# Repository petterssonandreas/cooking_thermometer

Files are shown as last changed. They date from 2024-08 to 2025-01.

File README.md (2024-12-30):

# cooking_thermometer

Simple electronics and SW project for creating a digital cooking/meat thermometer.

A probe from an old broken thermometer is used. The probe appears to be an NTC with around 200k resistance at 25C. Tests done at different temps to get a curve for the probe, curve can be found in `adc.c`.

The probe is connected to the HW via a 2.5mm "mono" jack with tip detection.

The processor used is an STM32G0B0KE with 512 kB flash and 144 kB SRAM. It comes in a LQFP32 package.

The product is powered via USB or via a 3.6V Li-ion battery, which is also charged when USB is connected. The battery is recycled from another old product. A small MCP73831 is used for the battery charging.

A small OLED display is used to display temperature and other info.

An active buzzer is used for the alarm functionality.

The system runs on 3.3 V.

# Zephyr installation

### Clone this repo
```
git clone git@github.com:petterssonandreas/cooking_thermometer.git
```

### Create a virtualenv, source it
```
python3 -m venv .venv
source .venv/Scripts/activate
```

### Install west
```
pip3 install west
```

### Init west with local repo, update
```
west init -l cooking_thermometer/
west update
```

### Export CMake
```
west zephyr-export
```

### Install packages
```
west packages pip --install
```

### Install Zephyr SDK
```
west sdk install
```

# Project build and flash
```
west build -p always -b ct_g0b0ke cooking_thermometer/apps/ct/
west flash
```

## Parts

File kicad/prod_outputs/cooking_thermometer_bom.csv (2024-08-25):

Id | Designator | Footprint | Quantity | Designation | Supplier and ref
1 | TP2 | TestPoint_Pad_D2.0mm | 1 | PC14
2 | R3,R6,R10 | R_1206_3216Metric_Pad1.30x1.75mm_HandSolder | 3 | 330
3 | SW4 | SW_PUSH_6mm | 1 | UI_B_SW
4 | R8,R9,R1,R2 | R_1206_3216Metric_Pad1.30x1.75mm_HandSolder | 4 | 100k
5 | SW5 | SW_PUSH_6mm | 1 | UI_C_SW
6 | U1 | LQFP-32_7x7mm_P0.8mm_Long_pads | 1 | STM32G0B0KETx
7 | C10,C3,C9 | C_1206_3216Metric_Pad1.33x1.80mm_HandSolder | 3 | 4.7uF
8 | J3 | PinHeader_1x02_P2.54mm_Vertical | 1 | 3V3_Power
9 | TP8 | TestPoint_Pad_D2.0mm | 1 | PB5
10 | R5 | R_1206_3216Metric_Pad1.30x1.75mm_HandSolder | 1 | 1k
11 | J4 | PinHeader_1x02_P2.54mm_Vertical | 1 | Battery
12 | C8,C4 | C_1206_3216Metric_Pad1.33x1.80mm_HandSolder | 2 | 100nF
13 | TP10 | TestPoint_Pad_D2.0mm | 1 | PB9
14 | D1 | D_DO-41_SOD81_P10.16mm_Horizontal | 1 | 1N5817
15 | D4 | LED_Rectangular_W5.0mm_H2.0mm | 1 | GREEN_LED_PWR
16 | J8 | Jack_Mono_2.5mm_with_Tip-Detect_Electrokit_41010270 | 1 | THERMO_CONN
17 | U3 | SOT-23-5_HandSoldering | 1 | MCP73831-2-OT
18 | U2 | TO-92_Inline | 1 | MCP1700x-330xxTO
19 | TP13 | TestPoint_Pad_D2.0mm | 1 | PA11/9
20 | J9 | USB_C_Receptacle_6P_TopMnt_Horizontal_Long_Pads_Electrokit_41021035 | 1 | USB_C
21 | TP9 | TestPoint_Pad_D2.0mm | 1 | PB8
22 | D3 | LED_Rectangular_W5.0mm_H2.0mm | 1 | RED_LED_CHARGING
23 | TP6 | TestPoint_Pad_D2.0mm | 1 | PB3
24 | TP5 | TestPoint_Pad_D2.0mm | 1 | PB1
25 | J2 | PinHeader_1x04_P2.54mm_Vertical | 1 | STLINK
26 | J7 | PinHeader_1x02_P2.54mm_Vertical | 1 | 5V_Power
27 | R7 | R_1206_3216Metric_Pad1.30x1.75mm_HandSolder | 1 | 4k7
28 | TP14 | TestPoint_Pad_D2.0mm | 1 | PA12/10
29 | R11 | R_1206_3216Metric_Pad1.30x1.75mm_HandSolder | 1 | 10k
30 | TP1 | TestPoint_Pad_D2.0mm | 1 | PC6
31 | BZ1 | Buzzer_12x9.5RM7.6 | 1 | Passive_Buzzer
32 | C2,C1 | C_1206_3216Metric_Pad1.33x1.80mm_HandSolder | 2 | 1uF
33 | Q1 | TO-92L_Inline_Wide | 1 | BC547
34 | TP4 | TestPoint_Pad_D2.0mm | 1 | PB0
35 | TP11 | TestPoint_Pad_D2.0mm | 1 | PA0
36 | SW1 | SW_PUSH_6mm | 1 | BOOT0_SW
37 | TP12 | TestPoint_Pad_D2.0mm | 1 | PA1
38 | TP15 | TestPoint_Pad_D2.0mm | 1 | PA15
39 | J1 | PinHeader_1x06_P2.54mm_Vertical | 1 | FTDI
40 | J6 | PinHeader_1x04_P2.54mm_Vertical | 1 | OLED_CONN
41 | R4 | R_1206_3216Metric_Pad1.30x1.75mm_HandSolder | 1 | 2k
42 | SW2 | SW_PUSH_6mm | 1 | NRST_SW
43 | TP3 | TestPoint_Pad_D2.0mm | 1 | PC15
44 | SW3 | SW_PUSH_6mm | 1 | UI_A_SW
45 | TP7 | TestPoint_Pad_D2.0mm | 1 | PB4
46 | D2 | LED_D4.0mm | 1 | WHITE_LED

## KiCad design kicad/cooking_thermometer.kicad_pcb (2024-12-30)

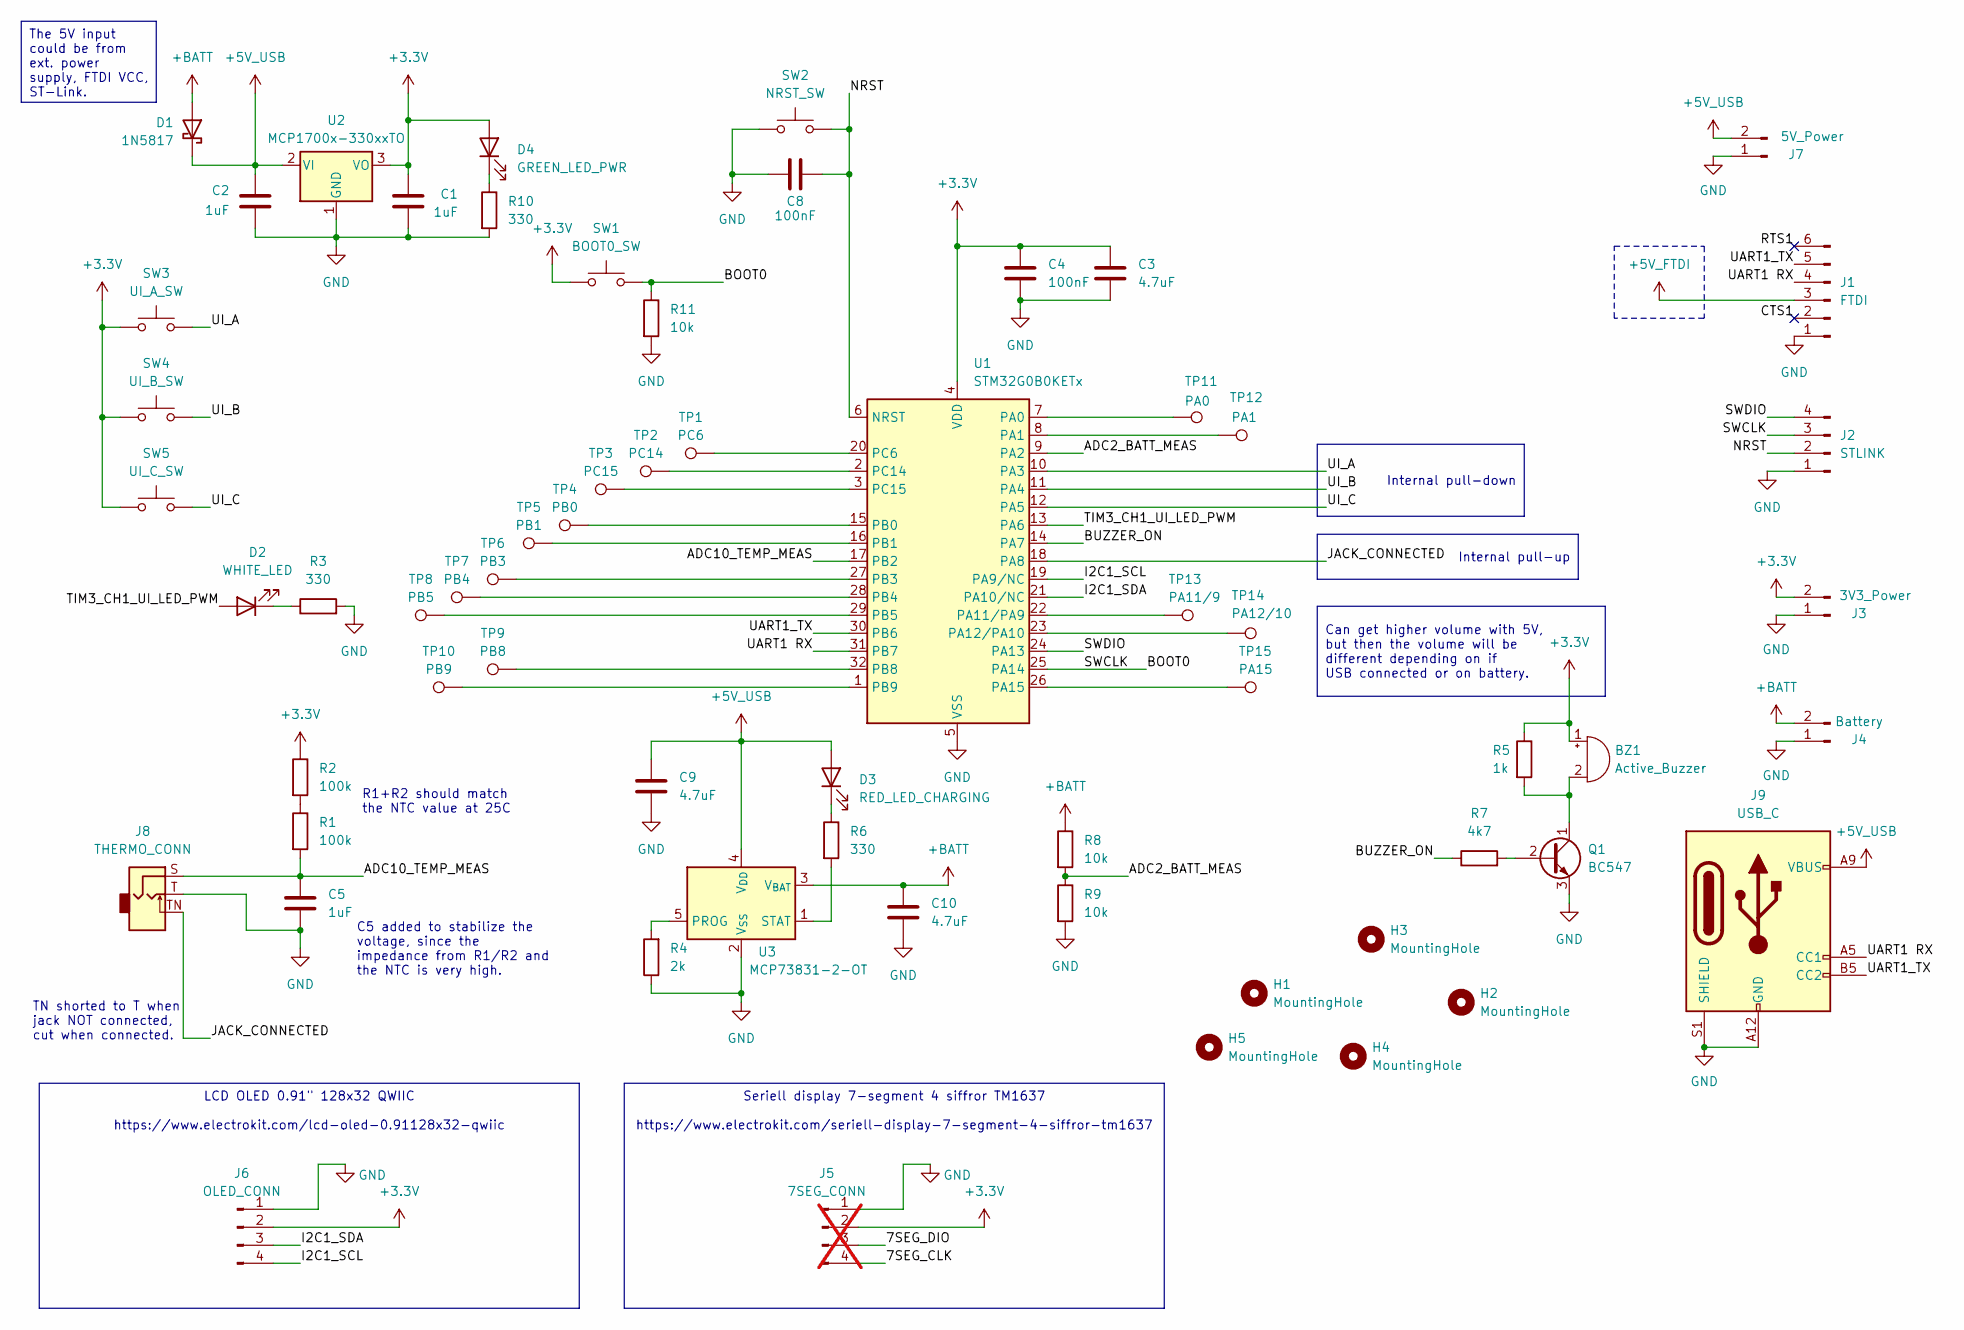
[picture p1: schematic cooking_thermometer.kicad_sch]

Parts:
BZ1: Active_Buzzer; Buzzer_12x9.5RM7.6
C1, C2, C5: 1uF; C_1206_3216Metric_Pad1.33x1.80mm_HandSolder
C3, C9, C10: 4.7uF; C_1206_3216Metric_Pad1.33x1.80mm_HandSolder
C4, C8: 100nF; C_1206_3216Metric_Pad1.33x1.80mm_HandSolder
D1: 1N5817; D_DO-41_SOD81_P10.16mm_Horizontal
D2: WHITE_LED; LED_D4.0mm
D3: RED_LED_CHARGING; LED_Rectangular_W5.0mm_H2.0mm
D4: GREEN_LED_PWR; LED_Rectangular_W5.0mm_H2.0mm
H1, H2, H3, H4, H5: MountingHole; MountingHole_3.2mm_M3
J1: FTDI; PinHeader_1x06_P2.54mm_Vertical
J2: STLINK; PinHeader_1x04_P2.54mm_Vertical
J3: 3V3_Power; PinHeader_1x02_P2.54mm_Vertical
J4: Battery; PinHeader_1x02_P2.54mm_Vertical
J5: 7SEG_CONN; PinSocket_1x04_P2.54mm_Vertical; not fitted
J6: OLED_CONN; PinHeader_1x04_P2.54mm_Vertical
J7: 5V_Power; PinHeader_1x02_P2.54mm_Vertical
J8: THERMO_CONN; Jack_Mono_2.5mm_with_Tip-Detect_Electrokit_41010270
J9: USB_C; USB_C_Receptacle_6P_TopMnt_Horizontal_Long_Pads_Electrokit_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
Q1: BC547; TO-92L_Inline_Wide
R1, R2: 100k; R_1206_3216Metric_Pad1.30x1.75mm_HandSolder
R3, R6, R10: 330; R_1206_3216Metric_Pad1.30x1.75mm_HandSolder
R4: 2k; R_1206_3216Metric_Pad1.30x1.75mm_HandSolder
R5: 1k; R_1206_3216Metric_Pad1.30x1.75mm_HandSolder
R7: 4k7; R_1206_3216Metric_Pad1.30x1.75mm_HandSolder
R8, R9, R11: 10k; R_1206_3216Metric_Pad1.30x1.75mm_HandSolder
SW1: BOOT0_SW; SW_PUSH_6mm
SW2: NRST_SW; SW_PUSH_6mm
SW3: UI_A_SW; SW_PUSH_6mm
SW4: UI_B_SW; SW_PUSH_6mm
SW5: UI_C_SW; SW_PUSH_6mm
TP1: PC6; TestPoint_Pad_D2.0mm
TP2: PC14; TestPoint_Pad_D2.0mm
TP3: PC15; TestPoint_Pad_D2.0mm
TP4: PB0; TestPoint_Pad_D2.0mm
TP5: PB1; TestPoint_Pad_D2.0mm
TP6: PB3; TestPoint_Pad_D2.0mm
TP7: PB4; TestPoint_Pad_D2.0mm
TP8: PB5; TestPoint_Pad_D2.0mm
TP9: PB8; TestPoint_Pad_D2.0mm
TP10: PB9; TestPoint_Pad_D2.0mm
TP11: PA0; TestPoint_Pad_D2.0mm
TP12: PA1; TestPoint_Pad_D2.0mm
TP13: PA11/9; TestPoint_Pad_D2.0mm
TP14: PA12/10; TestPoint_Pad_D2.0mm
TP15: PA15; TestPoint_Pad_D2.0mm
U1: STM32G0B0KETx; LQFP-32_7x7mm_P0.8mm_Long_pads
U2: MCP1700x-330xxTO; TO-92_Inline
U3: MCP73831-2-OT; SOT-23-5_HandSoldering

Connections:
+3.3V: BZ1.1 (+), C1.1, C3.1, C4.1, D4.2 (A), J3.2, J5.2, J6.2, R2.1, R5.1, SW1.1, SW3.1, SW4.1, SW5.1, U1.4 (VDD), U2.3 (VO)
+5V_FTDI: J1.3
+5V_USB: C2.1, C9.1, D1.1 (K), D3.2 (A), J7.2, J9.A9 (VBUS), J9.B9 (VBUS), U2.2 (VI), U3.4 (V_{DD})
+BATT: C10.1, D1.2 (A), J4.2, R8.1, U3.3 (V_{BAT})
/ADC2_BATT_MEAS: R8.2, R9.1, U1.9 (PA2)
/ADC10_TEMP_MEAS: C5.1, J8.S, R1.2, U1.17 (PB2)
/BOOT0: J2.3, R11.1, SW1.2, U1.25 (PA14)
/BUZZER_ON: R7.1, U1.14 (PA7)
/CTS1: J1.2
/I2C1_SCL: J6.4, U1.19 (PA9/NC)
/I2C1_SDA: J6.3, U1.21 (PA10/NC)
/JACK_CONNECTED: J8.TN, U1.18 (PA8)
/NRST: C8.2, J2.2, SW2.2, U1.6 (NRST)
/RTS1: J1.6
/SWDIO: J2.4, U1.24 (PA13)
/TIM3_CH1_UI_LED_PWM: D2.2 (A), U1.13 (PA6)
/UART1 RX: J1.4, J9.A5 (CC1), U1.31 (PB7)
/UART1_TX: J1.5, J9.B5 (CC2), U1.30 (PB6)
/UI_A: SW3.2, U1.10 (PA3)
/UI_B: SW4.2, U1.11 (PA4)
/UI_C: SW5.2, U1.12 (PA5)
GND: C1.2, C2.2, C3.2, C4.2, C5.2, C8.1, C9.2, C10.2, J1.1, J2.1, J3.1, J4.1, J5.1, J6.1, J7.1, J8.T, J9.A12 (GND), J9.B12 (GND), J9.S1 (SHIELD), Q1.3 (E), R3.2, R4.1, R9.2, R10.2, R11.2, SW2.1, U1.5 (VSS), U2.1 (GND), U3.2 (V_{SS})
unnamed: BZ1.2 (-), Q1.1 (C), R5.2
unnamed: D2.1 (K), R3.1
unnamed: D3.1 (K), R6.1
unnamed: D4.1 (K), R10.1
unnamed: Q1.2 (B), R7.2
unnamed: R1.1, R2.2
unnamed: TP11.1, U1.7 (PA0)
unnamed: TP12.1, U1.8 (PA1)
unnamed: TP13.1, U1.22 (PA11/PA9)
unnamed: TP14.1, U1.23 (PA12/PA10)
unnamed: TP15.1, U1.26 (PA15)
unnamed: TP4.1, U1.15 (PB0)
unnamed: TP5.1, U1.16 (PB1)
unnamed: TP6.1, U1.27 (PB3)
unnamed: TP7.1, U1.28 (PB4)
unnamed: TP8.1, U1.29 (PB5)
unnamed: TP9.1, U1.32 (PB8)
unnamed: TP10.1, U1.1 (PB9)
unnamed: TP1.1, U1.20 (PC6)
unnamed: TP2.1, U1.2 (PC14)
unnamed: TP3.1, U1.3 (PC15)
unnamed: R4.2, U3.5 (PROG)
unnamed: R6.2, U3.1 (STAT)

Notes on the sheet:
Can get higher volume with 5V, but then the volume will be different depending on if USB connected or on battery.
LCD OLED 0.91" 128x32 QWIIC https://www.electrokit.com/lcd-oled-0.91128x32-qwiic
Internal pull-down
Internal pull-up
The 5V input could be from ext. power supply, FTDI VCC, ST-Link.
Seriell display 7-segment 4 siffror TM1637 https://www.electrokit.com/seriell-display-7-segment-4-siffror-tm1637
TN shorted to T when jack NOT connected, cut when connected.
R1+R2 should match the NTC value at 25C
C5 added to stabilize the voltage, since the impedance from R1/R2 and the NTC is very high.

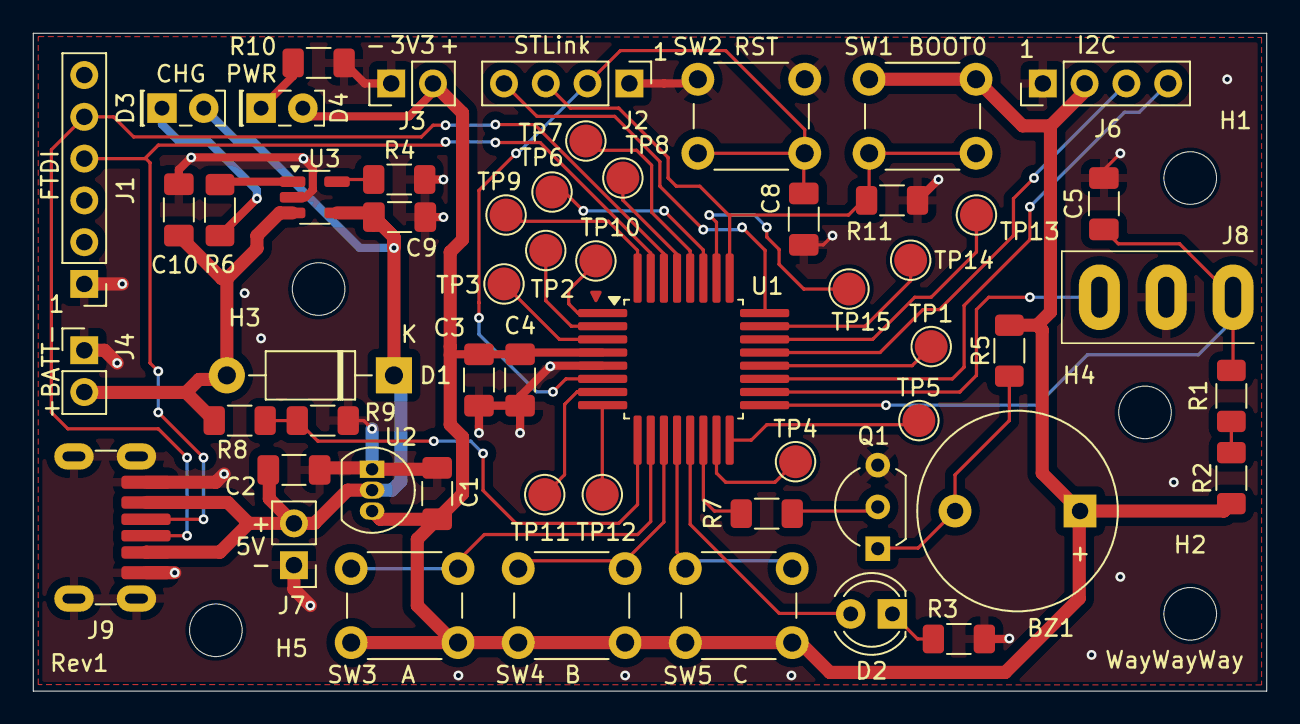
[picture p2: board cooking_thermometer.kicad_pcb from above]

Board: 2 copper layers, 75.0 x 40.0 mm, 61 parts (0 on the bottom side), 42 nets.

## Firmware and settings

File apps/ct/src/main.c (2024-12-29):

/*
 * Copyright (c) 2016 Open-RnD Sp. z o.o.
 * Copyright (c) 2020 Nordic Semiconductor ASA
 *
 * SPDX-License-Identifier: Apache-2.0
 */

#include "alarm.h"
#include "battery.h"
#include "state.h"
#include <zephyr/kernel.h>
#include <zephyr/device.h>
#include <zephyr/drivers/gpio.h>
#include <zephyr/drivers/pwm.h>
#include <zephyr/sys/util.h>
#include <zephyr/sys/printk.h>

#include <zephyr/logging/log.h>
LOG_MODULE_REGISTER(ct_main, CONFIG_CT_MAIN_LOG_LEVEL);

#include "adc.h"
#include "buttons.h"
#include "display.h"
#include "cttime.h"

static void set_target_temp_timer_expiry_function(struct k_timer *timer_id) {
    state_queue_entry_t queue_entry;
    queue_entry.event = STATE_EVENT_SET_TARGET_TEMP_TIMER_ELAPSED;
    if (k_msgq_put(&state_msgq, &queue_entry, K_NO_WAIT)) {
        LOG_WRN("Failed to put target temp timer event in msgq");
    }
}

K_TIMER_DEFINE(set_target_temp_timer, set_target_temp_timer_expiry_function, NULL);

static void check_inputs(void)
{
    state_queue_entry_t queue_entry;

    switch (state.state) {
    case STATE_IDLE:
        if (state.probe_connected && (state.temperature >= state.target_temperature)) {
            queue_entry.event = STATE_EVENT_TARGET_TEMP_REACHED;
            if (k_msgq_put(&state_msgq, &queue_entry, K_NO_WAIT)) {
                LOG_WRN("Failed to put target temp reached event in msgq");
            }
        }
        break;

    case STATE_TARGET_TEMP_REACHED:
    case STATE_TARGET_TEMP_REACHED_ACKED:
        if (!state.probe_connected || (state.temperature < state.target_temperature)) {
            queue_entry.event = STATE_EVENT_TARGET_TEMP_LOST;
            if (k_msgq_put(&state_msgq, &queue_entry, K_NO_WAIT)) {
                LOG_WRN("Failed to put target temp lost event in msgq");
            }
        }
        break;

    default:
        break;
    }
}

static void state_loop(void)
{
    int ret;
    state_queue_entry_t queue_entry;

    ret = k_msgq_get(&state_msgq, &queue_entry, K_MSEC(20));
    if (ret) {
        return;
    }

    switch (state.state) {
    case STATE_IDLE:
        switch (queue_entry.event) {
        case STATE_EVENT_BUTTON_PRESSED:
            if (queue_entry.data == 2) {
                state.state = STATE_SET_TARGET_TEMP;
                state_reset_blink_timer();
                k_timer_start(&set_target_temp_timer, K_SECONDS(5), K_NO_WAIT);
            }
            break;

        case STATE_EVENT_TARGET_TEMP_REACHED:
            state.state = STATE_TARGET_TEMP_REACHED;
            alarm_enable();
            break;

        default:
            break;
        }
        break;

    case STATE_TARGET_TEMP_REACHED:
        switch (queue_entry.event) {
        case STATE_EVENT_BUTTON_PRESSED:
            /* Allow any button to ack */
            state.state = STATE_TARGET_TEMP_REACHED_ACKED;
            alarm_disable();
            break;

        case STATE_EVENT_TARGET_TEMP_LOST:
            state.state = STATE_IDLE;
            alarm_disable();
            break;

        default:
            break;
        }
        break;

    case STATE_TARGET_TEMP_REACHED_ACKED:
        switch (queue_entry.event) {
        case STATE_EVENT_TARGET_TEMP_LOST:
            state.state = STATE_IDLE;
            alarm_disable();
            break;

        case STATE_EVENT_BUTTON_PRESSED:
            if (queue_entry.data == 2) {
                state.state = STATE_SET_TARGET_TEMP;
                state_reset_blink_timer();
                k_timer_start(&set_target_temp_timer, K_SECONDS(5), K_NO_WAIT);
            }
            break;

        default:
            break;
        }
        break;

    case STATE_SET_TARGET_TEMP:
        switch (queue_entry.event) {
        case STATE_EVENT_BUTTON_PRESSED:
            if (queue_entry.data == 0) {
                state.target_temperature++;
                state_reset_blink_timer();
                k_timer_start(&set_target_temp_timer, K_SECONDS(5), K_NO_WAIT);
            }
            else if (queue_entry.data == 1) {
                state.target_temperature--;
                state_reset_blink_timer();
                k_timer_start(&set_target_temp_timer, K_SECONDS(5), K_NO_WAIT);
            }
            else if (queue_entry.data == 2) {
                state.state = STATE_IDLE;
                k_timer_stop(&set_target_temp_timer);
            }
            break;

        case STATE_EVENT_SET_TARGET_TEMP_TIMER_ELAPSED:
            state.state = STATE_IDLE;
            break;

        default:
            break;
        }
        break;

    default:
        __ASSERT(false, "Bad state: %d", state.state);
        break;
    }
}

int main(void)
{
    int ret;

    LOG_INF("main starting");

    ret = state_init();
    if (ret) {
        LOG_ERR("Error %d: failed to init state", ret);
        return ret;
    }
    LOG_INF("state init done");

    ret = alarm_init();
    if (ret) {
        LOG_ERR("Error %d: failed to init alarm", ret);
        return ret;
    }
    LOG_INF("alarm init done");

    ret = buttons_init();
    if (ret != 0) {
        LOG_ERR("Error %d: failed to init buttons", ret);
        return ret;
    }
    LOG_INF("buttons init done");

    ret = cttime_init();
    if (ret) {
        LOG_ERR("Error %d: failed to init time", ret);
        return ret;
    }
    LOG_INF("Time init done");

    ret = adc_init();
    if (ret) {
        LOG_ERR("Error %d: failed to init ADC", ret);
        return ret;
    }
    LOG_INF("ADC init done");

    ret = battery_init();
    if (ret) {
        LOG_ERR("Error %d: failed to init battery", ret);
        return ret;
    }
    LOG_INF("battery init done");

    ret = display_init();
    if (ret) {
        LOG_ERR("Error %d: failed to init display", ret);
        return ret;
    }
    LOG_INF("Display init done");

    state.state = STATE_IDLE;

    while (true) {
        state_loop();
        check_inputs();
    }

    return 0;
}

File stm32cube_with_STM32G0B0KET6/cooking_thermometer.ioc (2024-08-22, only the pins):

Mcu.UserName=STM32G0B0KETx
PA10.Signal=I2C1_SDA
PA13.Signal=SYS_SWDIO
PA14-BOOT0.Signal=SYS_SWCLK
PA2.Signal=ADC1_IN2
PA3.GPIO_Label=UI_A
PA3.Signal=GPIO_Input
PA4.GPIO_Label=UI_B
PA4.Signal=GPIO_Input
PA5.GPIO_Label=UI_C
PA5.Signal=GPIO_Input
PA6.GPIO_Label=UI_LED
PA6.Signal=GPIO_Output
PA7.Signal=S_TIM3_CH2
PA8.GPIO_Label=nJACK_CONN
PA8.Signal=GPIO_Input
PA9.Signal=I2C1_SCL
PB2.Signal=ADC1_IN10
PB6.Signal=USART1_TX
PB7.Signal=USART1_RX

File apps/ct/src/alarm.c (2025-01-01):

#include "alarm.h"
#include "state.h"
#include <zephyr/kernel.h>
#include <zephyr/device.h>
#include <zephyr/drivers/pwm.h>
#include <zephyr/drivers/gpio.h>
#include <zephyr/sys/util.h>

#include <zephyr/logging/log.h>
LOG_MODULE_REGISTER(ct_alarm, CONFIG_CT_ALARM_LOG_LEVEL);

#define PWM_LED_PERIOD NSEC_PER_MSEC

#define ALARM_ON_TIME_MSEC 50
#define ALARM_OFF_TIME_MSEC 950

static const struct pwm_dt_spec ui_led = PWM_DT_SPEC_GET(DT_ALIAS(uiled));
static const struct gpio_dt_spec buzzer = GPIO_DT_SPEC_GET(DT_ALIAS(buzzer), gpios);

static struct k_timer alarm_timer;

static uint32_t current_ui_led_pulse = 0;

static void alarm_timer_expiry_function(struct k_timer *timer_id)
{
    k_timeout_t timeout;

    if (current_ui_led_pulse > 0) {
        pwm_set_pulse_dt(&ui_led, 0);
        current_ui_led_pulse = 0;
        timeout = K_MSEC(ALARM_OFF_TIME_MSEC);
    }
    else {
        pwm_set_pulse_dt(&ui_led, PWM_LED_PERIOD);
        current_ui_led_pulse = PWM_LED_PERIOD;
        timeout = K_MSEC(ALARM_ON_TIME_MSEC);
    }

    gpio_pin_toggle_dt(&buzzer);
    k_timer_start(&alarm_timer, timeout, K_NO_WAIT);
}

static void alarm_timer_stop_function(struct k_timer *timer_id)
{
    pwm_set_pulse_dt(&ui_led, 0);
    current_ui_led_pulse = 0;
    gpio_pin_set_dt(&buzzer, 0);
}

int alarm_init(void)
{
    int ret;

    if (!gpio_is_ready_dt(&buzzer)) {
        LOG_ERR("Error: buzzer GPIO is not ready");
        return -ENODEV;
    }
    ret = gpio_pin_configure_dt(&buzzer, GPIO_OUTPUT_INACTIVE);
    if (ret < 0) {
        LOG_ERR("Error %d: failed to configure buzzer gpio", ret);
        return ret;
    }

    if (!pwm_is_ready_dt(&ui_led)) {
        LOG_ERR("Error: PWM device %s is not ready", ui_led.dev->name);
        return -ENODEV;
    }
    ret = pwm_set_dt(&ui_led, PWM_LED_PERIOD, 0);
    if (ret < 0) {
        LOG_ERR("Error %d: failed to set pulse width", ret);
        return ret;
    }
    LOG_INF("PWM LEDs init done");


    k_timer_init(&alarm_timer, alarm_timer_expiry_function, alarm_timer_stop_function);
    /* Don't start timer here */

    return 0;
}

void alarm_enable(void)
{
    k_timer_start(&alarm_timer, K_NO_WAIT, K_NO_WAIT);
}

void alarm_disable(void)
{
    k_timer_stop(&alarm_timer);
}

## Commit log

2024-08-04 Add STM32Cube file with pinout, no RTOS stuff done yet
2024-08-04 Add Kicad files, ignore caches and such
    [cooking_thermometer.kicad_pcb, cooking_thermometer.kicad_sch]
2024-08-04 Add passive buzzer to schematic, layout, stm32cube
    [cooking_thermometer.kicad_pcb, cooking_thermometer.kicad_sch]
2024-08-08 Generate code from STM32CubeMX
2024-08-09 Rearrange signals to better fit board
    [cooking_thermometer.kicad_pcb, cooking_thermometer.kicad_sch]
2024-08-11 Change schematic/layout to stm32g0b0ke (LQFP32)
    [cooking_thermometer.kicad_pcb, cooking_thermometer.kicad_sch]
2024-08-22 Change to longer pads and some other adjustments
    [cooking_thermometer.kicad_pcb, cooking_thermometer.kicad_sch]
2024-08-22 Add stm32cubemx file
2024-08-24 Add +- to battery connection
    [cooking_thermometer.kicad_pcb]
2024-08-24 Remove old stm32cube, create new for stm32g0b0ke
2024-08-24 Change 2.5mm jack, make the board bigger, add mounting holes. Some rewiring.
    [cooking_thermometer.kicad_pcb, cooking_thermometer.kicad_sch]
2024-08-25 Add extra series on pullup NTC. Move stuff around.
    [cooking_thermometer.kicad_pcb, cooking_thermometer.kicad_sch]
2024-08-25 Set min track clearance to 6mils
    [cooking_thermometer.kicad_pcb]
2024-08-25 Final silk fixes
    [cooking_thermometer.kicad_pcb]
2024-08-25 Create all necessary outputs for rev1 production
    [cooking_thermometer-B_Cu.gbr, cooking_thermometer-B_Mask.gbr, cooking_thermometer-B_Paste.gbr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]
2024-10-20 Add board with only basic stuff
    Works with basic blinky sample
2024-12-27 Use pwm led, and add buzzer gpio
    [buttons.c, main.c]
2024-12-27 Add KiCad lock files to gitignore
2024-12-27 Add display on i2c
2024-12-28 Add ADC
2024-12-29 Get temperature from NTC
2024-12-29 Add jack/probe check, improve display
2024-12-29 Add battery level calc and display
2024-12-29 Add target temperature and ability to set it
2024-12-30 Update schematic and board
    Add C5 for temperature input stabilization
    Rename UI led and buzzer to correctly denote PWM usage
    [cooking_thermometer.kicad_pcb, cooking_thermometer.kicad_sch]
2025-01-01 Add battery shell cmd
